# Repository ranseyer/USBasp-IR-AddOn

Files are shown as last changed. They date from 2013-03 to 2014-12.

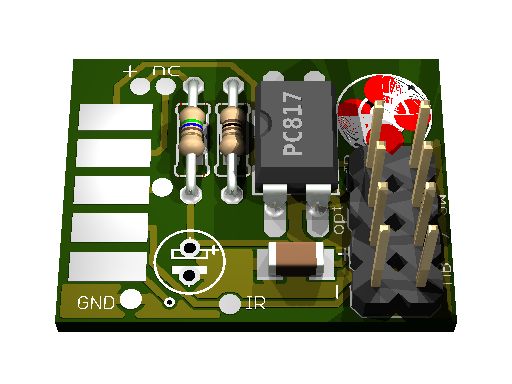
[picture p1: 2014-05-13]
HW/2.Medium/Add-OnV20-final-parts.jpg

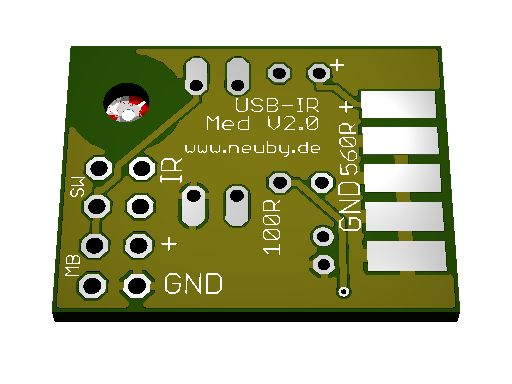
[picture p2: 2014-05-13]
HW/2.Medium/Add-OnV20-final-bot.jpg

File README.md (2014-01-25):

USBasp-IR-AddOn
===============

IR-Reciver  Extension for USBASP

ir_control, 1.0.0 (20.05.2012) control the "USB IR Remote Receiver"
 (www.mikrocontroller.net/articles/USB_IR_Remote_Receiver).

ir_control [-h] | [-V] | [[[-d] | [-p[1|0]] | [-rCOUNT] | [-s] | [-t]] [-i]]

  -h              print this help and exit
  -V              print version and exit

  -d              delete the PowerOn IR code.
                  The next received code becomes the new PowerOn code
  -p [1|0]        set PowerOn (ON=1/OFF=0)
  -r COUNT        set repeat count (default=5)
  -s              status of: PowerOn (ON=1/OFF=0)
  -i              ignore device name. (just checks the vendor:device ID)
                  needs one of the other options.

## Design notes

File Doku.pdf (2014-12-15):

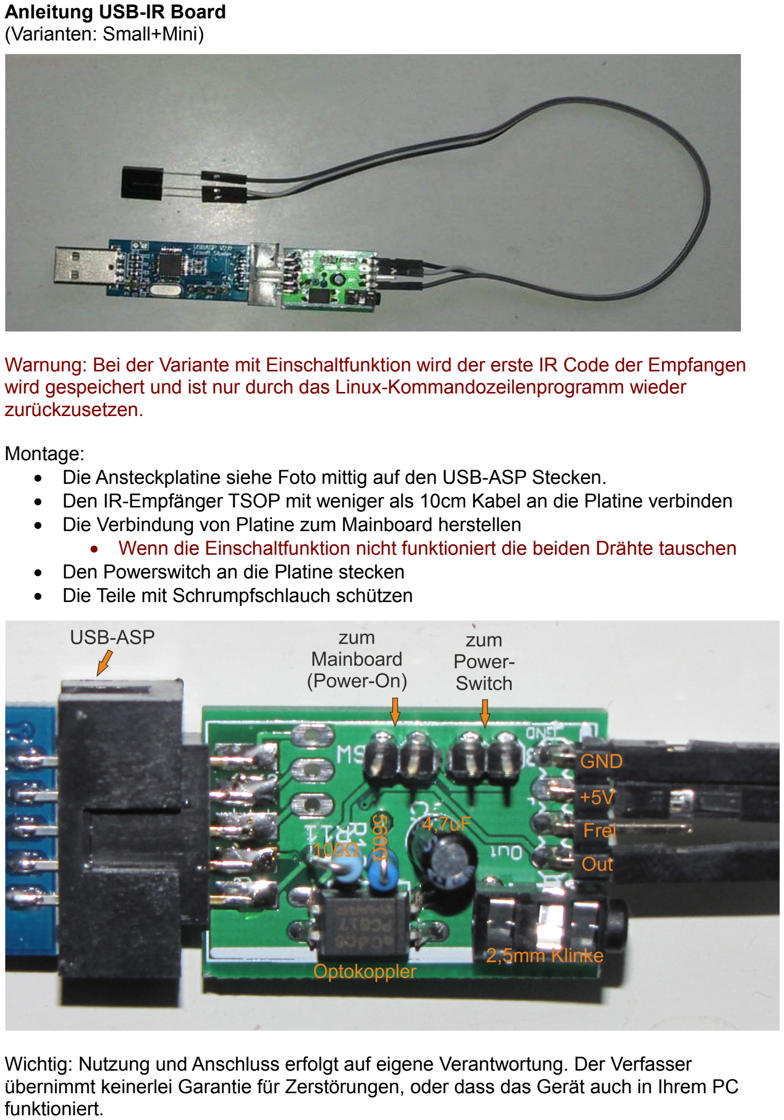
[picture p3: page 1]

Anleitung USB-IR Board
(Varianten: Small+Mini)

Warnung: Bei der Variante mit Einschaltfunktion wird der erste IR Code der Empfangen wird gespeichert und ist nur durch das Linux-Kommandozeilenprogramm wieder zurückzusetzen.

Montage:
- Die Ansteckplatine siehe Foto mittig auf den USB-ASP Stecken.
- Den IR-Empfänger TSOP mit weniger als 10cm Kabel an die Platine verbinden
- Die Verbindung von Platine zum Mainboard herstellen
- Wenn die Einschaltfunktion nicht funktioniert die beiden Drähte tauschen
- Den Powerswitch an die Platine stecken
- Die Teile mit Schrumpfschlauch schützen

Wichtig: Nutzung und Anschluss erfolgt auf eigene Verantwortung. Der Verfasser übernimmt keinerlei Garantie für Zerstörungen, oder dass das Gerät auch in Ihrem PC funktioniert.

Anschlussbelegung V2 Platine

Inbetriebnahme allgemein
A) Den „Stick“ einstecken und auf der Fernbediernung die Power-Taste drücken um den Einschaltcode anzulernen. Nach dem Anlernen den Stick kurz ziehen und wieder stecken. Der Einschaltcode wird nicht zum PC durchgereicht, sondern geht direkt zum Mainboardanschluss.
B) Wenn kein Einschaltcode genutzt werden soll, eine Taste einer unwichtigen Fernbedienung anlernen.
C) Stick ziehen und wieder einstecken

Inbetriebnahme Softwareseitig
Mögliche Varianten:
A) Bei easyVDR 2.0: einfach die Fragen bei der Installation korrekt beantworten
B) Andere Ubuntu/Debian Distributionen die Pakete von hier testen: https://launchpad.net/~martin-neuby/+archive/usb-irmp Diese sollten Versionsunabhängig sein...

Weitere Informationen / Links http://wiki.easy-vdr.de/index.php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 (http://www.vdr-portal.de/board18-vdr-hardware/board13-fernbedienungen/p1036294-irmplircd-f%C3%BCr-usb-ir-remote-receiver-based-on-irmp/)

V1.3 Martin Neubauer

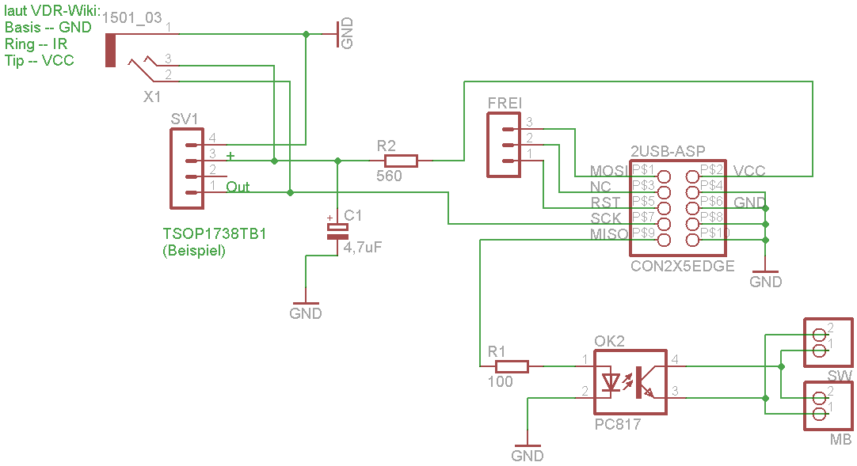
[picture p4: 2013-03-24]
HW/2.Medium/SchematicV13.png

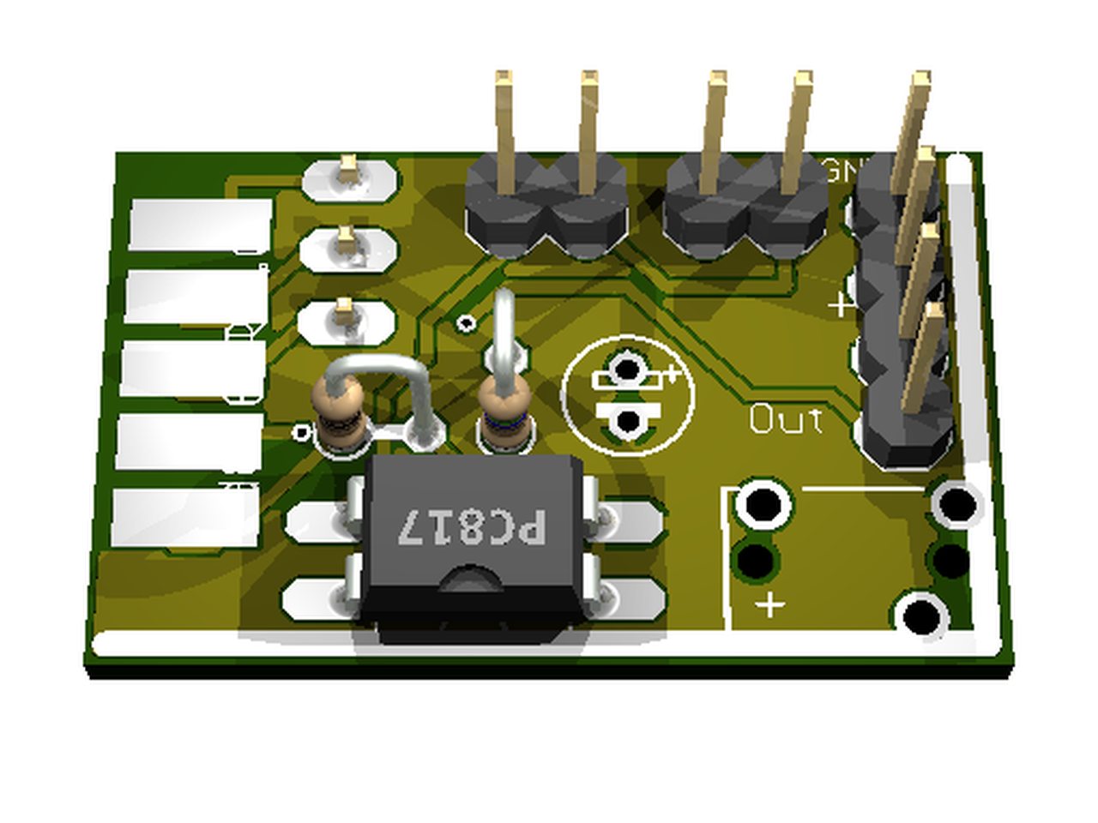
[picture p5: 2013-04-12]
HW/2.Medium/Add-OnV12-top.jpg

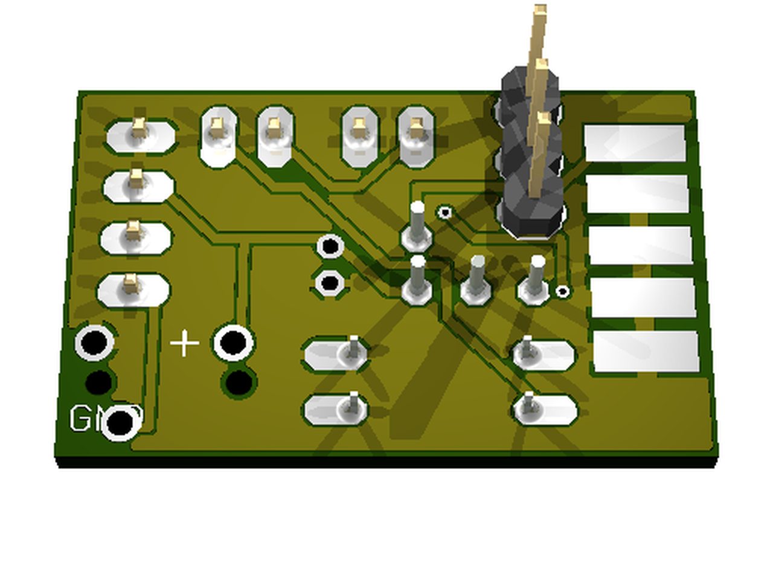
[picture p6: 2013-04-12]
HW/2.Medium/Add-OnV12-bot.jpg

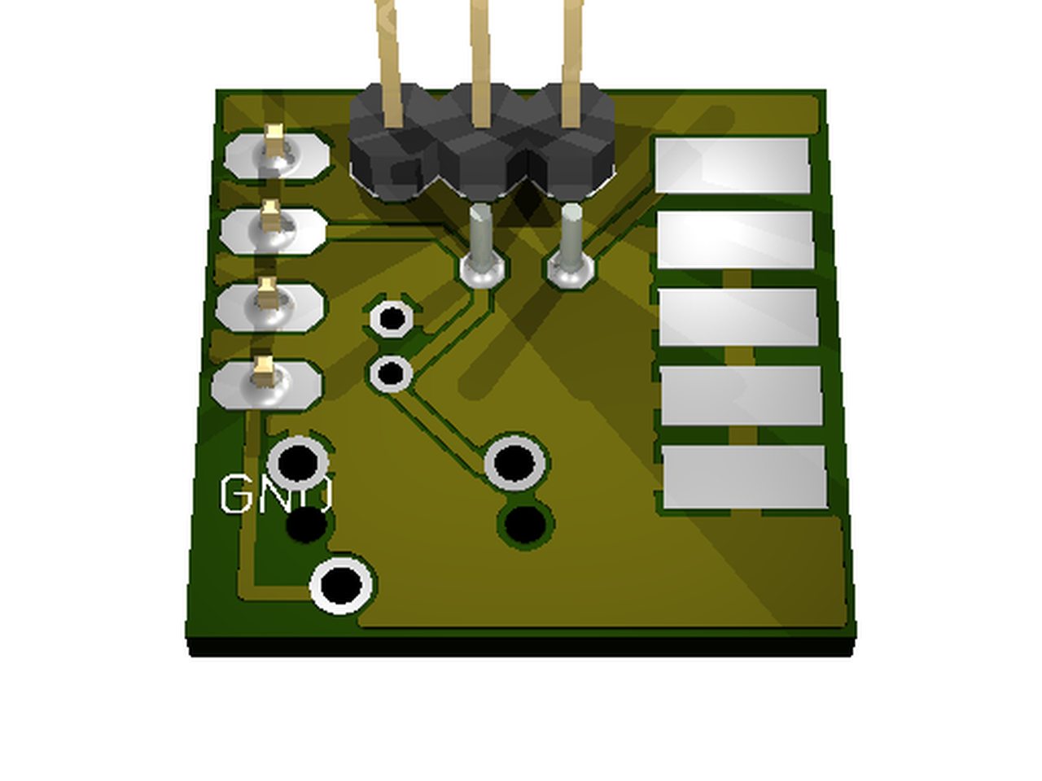
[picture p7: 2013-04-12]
HW/1.Mini/MiniAdd-OnV11-bot.jpg

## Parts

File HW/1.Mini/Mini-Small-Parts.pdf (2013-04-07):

### Tabelle1

Mini-Version

Part | | Device | | Preis
2USB-ASP CON2X5EDGE CON2X5EDGE | MPE 094-2-010 | 0,34
C1 | 4,7uF | CPOL-EUE1.8-4 SM 4,7/50RAD | 0,1
FREI | | MA03-1 | - | 0
R2 | | 560 R-EU_0204/2V | METALL 560 | 0,1
SV1 | | MA04-1 | SL 1X40G 2,54 (optional; Anteilig 10%) | 0,26
X1 | 1501_03 | 1501_03 | LUM 1501-03 | 0,7
Part | Device | Preis
2USB-ASP CON2X5EDGE CON2X5EDGE | SL 2X25G 2,54 (Anteilig 20%)
C1 | 4,7uF | CPOL-EUE1.8-4 SM 4,7/50RAD
FREI | | MA03-1 | optional
MB | | PINHD-1X2 | SL 1X40G 2,54 (optional; Anteilig 10%)
OK2 | PC817 | PC817 | PC 817X
R1 | | 100 R-EU_0204/2V | METALL 100
R2 | | 560 R-EU_0204/2V | METALL 560
SV1 | | MA04-1 | siehe MB
SW | | PINHD-1X2 | siehe MB
X1 | 1501_03 | 1501_03 | LUM 1501-03

Zusätzlich TSOP nach Wahl !

Partlist

Value | Reichelt
Partlist | Small-Version
Value | Reichelt

### Tabelle1

CON2X5EDGE | 1
E1,8-4 | 1
MA03-1 | 1
0204V | 1
MA04-1 | 1
1501_03 | 1
CON2X5EDGE | 1
E1,8-4 | 1
MA03-1 | 1
1X02 | 1
DIL04 | 1
0204V | 1
0204V | 1
MA04-1 | 1
1X02 | 1
1501_03 | 1
Package | Library | Sheet
| schwen rcl con-lstb rcl con-lstb

con-lumberg

Package | Library | Sheet
| schwen rcl con-lstb pinhead

optocoupler
| rcl rcl con-lstb pinhead

con-lumberg

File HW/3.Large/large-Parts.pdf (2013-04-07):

Tabelle1

Part | | Device | | Preis
C1 | 4u7 | C-EUC0805 | X5R-G0805 4,7 | 0,05
C2 | 10uF | CPOL-EU085CS-1AR | X7R-G1210 10 | 0,48
C3 | 100n | C-EUC0805 | X7R-G0603 100N0,05 | 0,05
C4 | 22p | C-EUC0805 | NPO-G0603 22P | 0,05
C5 | 22p | C-EUC0805 | | 0,05
CFG | | MA03-2 | SL 2X25G 2,54 (Anteilig 5%)
D1 | 3V6 | ZENER-DIODESOD80C | SMD ZF 3,6 | 0,05
D2 | 3V6 | ZENER-DIODESOD80C | SMD ZF 3,6 | 1,05
IC1 | MEGA48A-AU MEGA8-AI | ATMEGA 168A-AU
IR | | MA04-1 | SL 1X40G 2,54 (optional; Anteilig 10%)
ISP | | MA05-2 | SL 2X25G 2,54 (Anteilig 20%)
LED1 | | LEDCHIPLED_1206 | SMD-LED 1206 GN | 0,13
LED2 | | LEDCHIPLED_1206 | SMD-LED 1206 RT | 0,1
MB-SW | MA04-1 | SL 1X50W 2,54 oder SL 1X40G 2,54 (optional; Anteilig 10%) 0,1
OPT | | MA03-2 | Optional Teil von „SL 2X25G 2,54“ | 0,2
Q2 | | CRYSTALHC49UP | 12,0000-HC49-SMD | 0,24
R1 | | 68 R-EU_M0805 | SMD-0805 68,0 | 0,1
R2 | | 68 R-EU_M0805 | s.o. | 0,1
R3 | 2k2 | R-EU_M0805 | SMD-0805 2,20K | 0,1
R4 | 1k | R-EU_M0805 | SMD-0805 1,00K | 0,1
R5 | 1k | R-EU_M0805 | s.o. | 0,1
R6 | 10k | R-EU_M0805 | SMD-0805 10,0K | 0,1
R7 | 1k | R-EU_M0805 | s.o. | 0,1
R8 | 560 R-EU_M0805 | SMD-0805 560 | 0,1
R9 | 560 R-EU_M0805 | s.o. | 0,1
SV2 | | FE05W | MPE 094-1-005 | 0,26
X1 | 1501_031501_03 | LUM 1501-03 | 0,7
| | | Summe | 2,63
K2 | | 35701331 Optional SIL 7271-D 5V | 1,5
OK1 | PC817 PC817 | Optional PC 817X | 0,35
| 38KHz | TSOP 31238 | 0,77
| 56KHz | TSOP 31256 | 0,8

Partlist

Value | Reichelt

NPO-G0603 22P

green
red

Tabelle1

C0805
085CS_1AR
C0805
C0805
C0805
MA03-2
SOD80C
SOD80C
TQFP32-08
MA04-1
MA05-2
CHIPLED_1206
CHIPLED_1206
MA04-1
MA03-2
HC49UP
M0805
M0805
M0805
M0805
M0805
M0805
M0805
M0805
M0805
FE05W
1501_03

REED
DIL04
Package | Library
| rcl rcl rcl rcl rcl con-lstb diode diode atmel con-lstb con-lstb led led con-lstb con-lstb crystal rcl rcl rcl rcl rcl rcl rcl rcl rcl con-lsta con-lumberg

relay
optocoupler

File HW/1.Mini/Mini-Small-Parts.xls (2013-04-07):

Partlist | Mini-Version
Part | Value | Device | Reichelt | Preis | Package | Library | Sheet
2USB-ASP | CON2X5EDGE | CON2X5EDGE | MPE 094-2-010 | 0.34 | CON2X5EDGE | schwen | 1
C1 | 4,7uF | CPOL-EUE1.8-4 | SM 4,7/50RAD | 0.1 | E1,8-4 | rcl | 1
FREI |  | MA03-1 | - | 0 | MA03-1 | con-lstb | 1
R2 | 560 | R-EU_0204/2V | METALL 560 | 0.1 | 0204V | rcl | 1
SV1 |  | MA04-1 | SL 1X40G 2,54 (optional; Anteilig 10%) | 0.26 | MA04-1 | con-lstb | 1
X1 | 1501_03 | 1501_03 | LUM 1501-03 | 0.7 | 1501_03 | con-lumberg | 1
 |  |  | Summe | 1.5
Partlist | Small-Version
Part | Value | Device | Reichelt | Preis | Package | Library | Sheet
2USB-ASP | CON2X5EDGE | CON2X5EDGE | SL 2X25G 2,54 (Anteilig 20%) |  | CON2X5EDGE | schwen | 1
C1 | 4,7uF | CPOL-EUE1.8-4 | SM 4,7/50RAD |  | E1,8-4 | rcl | 1
FREI |  | MA03-1 | optional |  | MA03-1 | con-lstb | 1
MB |  | PINHD-1X2 | SL 1X40G 2,54 (optional; Anteilig 10%) |  | 1X02 | pinhead | 1
OK2 | PC817 | PC817 | Optional PC 817X |  | DIL04 | optocoupler | 1
R1 | 100 | R-EU_0204/2V | METALL 100 |  | 0204V | rcl | 1
R2 | 560 | R-EU_0204/2V | METALL 560 |  | 0204V | rcl | 1
SV1 |  | MA04-1 | siehe MB |  | MA04-1 | con-lstb | 1
SW |  | PINHD-1X2 | siehe MB |  | 1X02 | pinhead | 1
X1 | 1501_03 | 1501_03 | LUM 1501-03 |  | 1501_03 | con-lumberg | 1
Zusätzlich TSOP nach Wahl !
OK1 | PC817 | PC817 | Optional PC 817X | 0.35 | DIL04 | optocoupler
 | 38KHz |  | TSOP 31238 | 0.77
 | 56KHz |  | TSOP 31256 | 0.8

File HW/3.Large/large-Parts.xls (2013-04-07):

Partlist
Part | Value | Device | Reichelt | Preis | Package | Library
C1 | 4u7 | C-EUC0805 | X5R-G0805 4,7 | 0.05 | C0805 | rcl
C2 | 10uF | CPOL-EU085CS-1AR | X7R-G1210 10 | 0.48 | 085CS_1AR | rcl
C3 | 100n | C-EUC0805 | X7R-G0603 100N0,05 | 0.05 | C0805 | rcl
C4 | 22p | C-EUC0805 | NPO-G0603 22P | 0.05 | C0805 | rcl
C5 | 22p | C-EUC0805 | NPO-G0603 22P | 0.05 | C0805 | rcl
CFG |  | MA03-2 | SL 2X25G 2,54 (Anteilig 5%) |  | MA03-2 | con-lstb
D1 | 3V6 | ZENER-DIODESOD80C | SMD ZF 3,6 | 0.05 | SOD80C | diode
D2 | 3V6 | ZENER-DIODESOD80C | SMD ZF 3,6 | 1.05 | SOD80C | diode
IC1 | MEGA48A-AU | MEGA8-AI | ATMEGA 168A-AU |  | TQFP32-08 | atmel
IR |  | MA04-1 | SL 1X40G 2,54 (optional; Anteilig 10%) |  | MA04-1 | con-lstb
ISP |  | MA05-2 | SL 2X25G 2,54 (Anteilig 20%) |  | MA05-2 | con-lstb
LED1 | green | LEDCHIPLED_1206 | SMD-LED 1206 GN | 0.13 | CHIPLED_1206 | led
LED2 | red | LEDCHIPLED_1206 | SMD-LED 1206 RT | 0.1 | CHIPLED_1206 | led
MB-SW |  | MA04-1 | SL 1X50W 2,54 oder SL 1X40G 2,54 (optional; Anteilig 10%) | 0.1 | MA04-1 | con-lstb
OPT |  | MA03-2 | Optional Teil von „SL 2X25G 2,54“ | 0.2 | MA03-2 | con-lstb
Q2 |  | CRYSTALHC49UP | 12,0000-HC49-SMD | 0.24 | HC49UP | crystal
R1 | 68 | R-EU_M0805 | SMD-0805 68,0 | 0.1 | M0805 | rcl
R2 | 68 | R-EU_M0805 | s.o. | 0.1 | M0805 | rcl
R3 | 2k2 | R-EU_M0805 | SMD-0805 2,20K | 0.1 | M0805 | rcl
R4 | 1k | R-EU_M0805 | SMD-0805 1,00K | 0.1 | M0805 | rcl
R5 | 1k | R-EU_M0805 | s.o. | 0.1 | M0805 | rcl
R6 | 10k | R-EU_M0805 | SMD-0805 10,0K | 0.1 | M0805 | rcl
R7 | 1k | R-EU_M0805 | s.o. | 0.1 | M0805 | rcl
R8 | 560 | R-EU_M0805 | SMD-0805 560 | 0.1 | M0805 | rcl
R9 | 560 | R-EU_M0805 | s.o. | 0.1 | M0805 | rcl
SV2 |  | FE05W | MPE 094-1-005 | 0.26 | FE05W | con-lsta
X1 | 1501_03 | 1501_03 | LUM 1501-03 | 0.7 | 1501_03 | con-lumberg
 |  |  | Summe | 2.63
K2 |  | 35701331 | Optional SIL 7271-D 5V | 1.5 | REED | relay
OK1 | PC817 | PC817 | Optional PC 817X | 0.35 | DIL04 | optocoupler
 | 38KHz |  | TSOP 31238 | 0.77
 | 56KHz |  | TSOP 31256 | 0.8

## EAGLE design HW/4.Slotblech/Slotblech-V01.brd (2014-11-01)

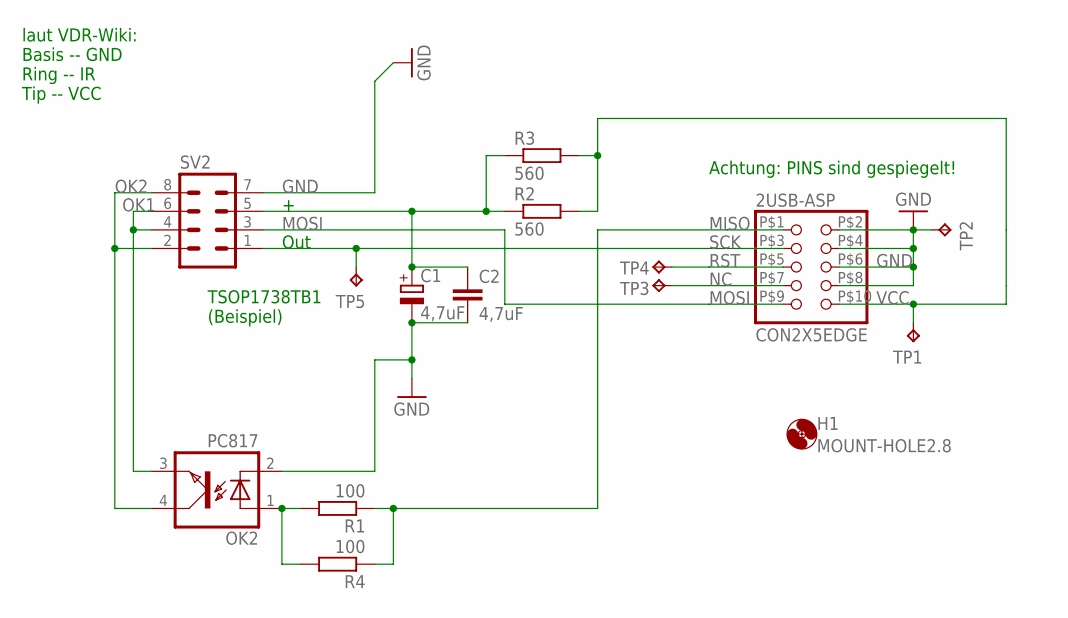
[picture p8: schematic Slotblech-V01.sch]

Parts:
2USB-ASP: CON2X5EDGE
C1: 4,7uF; E1,8-4
C2: 4,7uF; C1206K
H1: MOUNT-HOLE2.8; 2,8
OK2: PC817; DIL04
R1: 100; 0204/7
R2: 560; 0204/7
R3: 560; R0805W
R4: 100; R0805W
SV2: MA04-2
TP1, TP2, TP3, TP4, TP5: TPB1,27; B1,27

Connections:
GND: 2USB-ASP.P$2 (2), 2USB-ASP.P$4 (4), 2USB-ASP.P$6 (6), 2USB-ASP.P$8 (8), C1.-, C2.2, OK2.2 (C), SV2.7, TP2.TP
MISO: 2USB-ASP.P$1 (1), R1.1, R4.1
MOSI: 2USB-ASP.P$9 (9), SV2.3
unnamed: C1.+, C2.1, R2.1, R3.1, SV2.5
unnamed: OK2.1 (A), R1.2, R4.2
NC: 2USB-ASP.P$7 (7), TP3.TP
OK1: OK2.3 (EMIT), SV2.4, SV2.6
OK2: OK2.4 (COL), SV2.2, SV2.8
RST: 2USB-ASP.P$5 (5), TP4.TP
SCK: 2USB-ASP.P$3 (3), SV2.1, TP5.TP
VCC: 2USB-ASP.P$10 (10), R2.2, R3.2, TP1.TP

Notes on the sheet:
Achtung: PINS sind gespiegelt!
Out
laut VDR-Wiki: Basis -- GND Ring -- IR Tip -- VCC
TSOP1738TB1 (Beispiel)

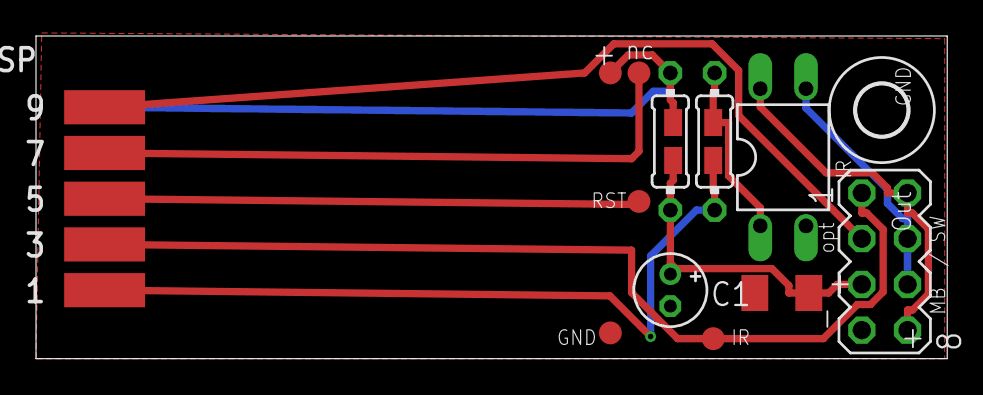
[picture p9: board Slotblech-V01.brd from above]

Board: 2 copper layers, 50.6 x 17.9 mm, 15 parts (0 on the bottom side), 11 nets.

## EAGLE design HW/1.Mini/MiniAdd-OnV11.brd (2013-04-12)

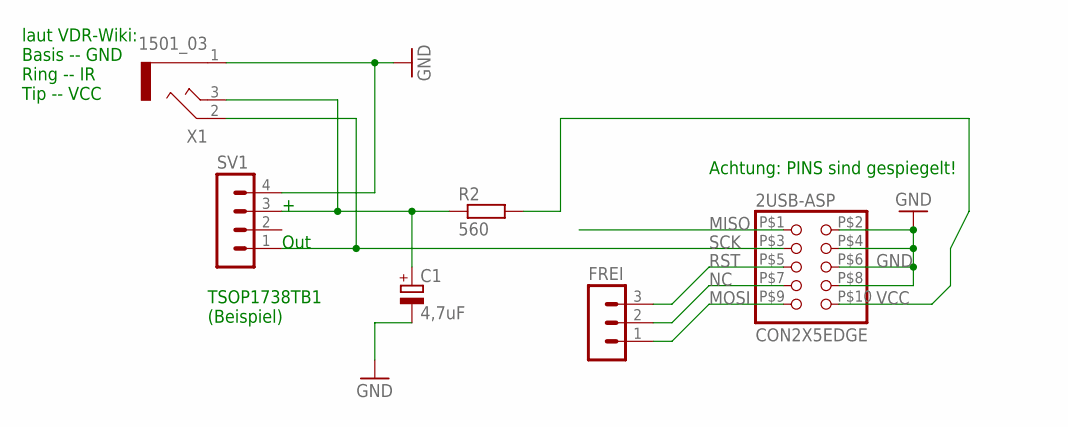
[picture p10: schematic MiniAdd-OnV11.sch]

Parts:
2USB-ASP: CON2X5EDGE
C1: 4,7uF; E1,8-4
FREI: MA03-1
R2: 560; 0204V
SV1: MA04-1
X1: 1501_03

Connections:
GND: 2USB-ASP.P$2 (2), 2USB-ASP.P$4 (4), 2USB-ASP.P$6 (6), 2USB-ASP.P$8 (8), C1.-, SV1.4, X1.1
MISO: 2USB-ASP.P$1 (1)
MOSI: 2USB-ASP.P$9 (9), FREI.1
unnamed: C1.+, R2.1, SV1.3, X1.3
NC: 2USB-ASP.P$7 (7), FREI.2
RST: 2USB-ASP.P$5 (5), FREI.3
SCK: 2USB-ASP.P$3 (3), SV1.1, X1.2
VCC: 2USB-ASP.P$10 (10), R2.2

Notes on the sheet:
Achtung: PINS sind gespiegelt!
Out
laut VDR-Wiki: Basis -- GND Ring -- IR Tip -- VCC
TSOP1738TB1 (Beispiel)

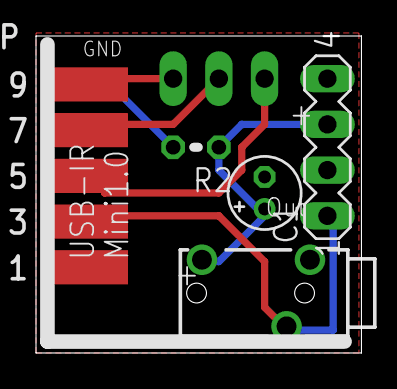
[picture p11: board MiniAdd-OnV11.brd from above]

Board: 2 copper layers, 18.1 x 17.6 mm, 6 parts (1 on the bottom side), 7 nets.

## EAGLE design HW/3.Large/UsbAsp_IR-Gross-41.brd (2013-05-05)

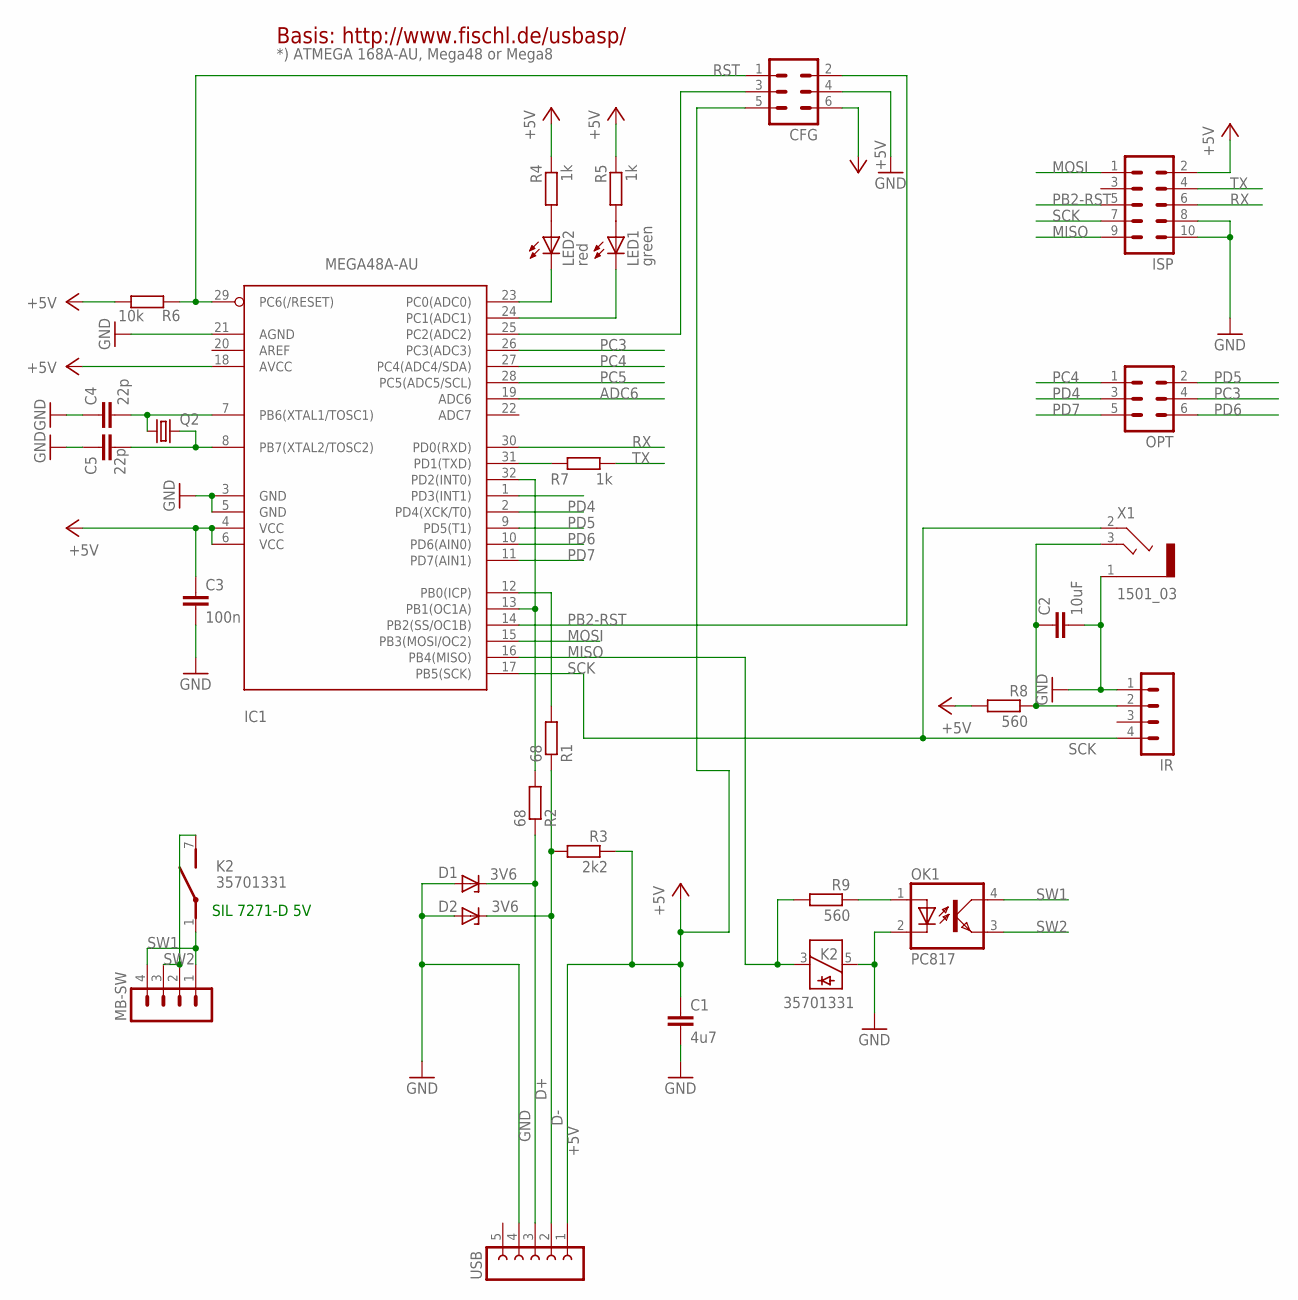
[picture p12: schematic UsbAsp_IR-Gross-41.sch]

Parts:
C1: 4u7; C0805
C2: 10uF; C1210
C3: 100n; C0805
C4, C5: 22p; C0805
CFG: MA03-2
D1, D2: 3V6; SOD80C
IC1: MEGA48A-AU; TQFP32-08
IR: MA04-1
ISP: MA05-2
K2: 35701331; REED
LED1: green; CHIPLED_1206
LED2: red; CHIPLED_1206
MB-SW: MA04-1
OK1: PC817; DIL04
OPT: MA03-2
Q2: CRYSTALHC49UP; HC49UP
R1, R2: 68; M0805
R3: 2k2; M0805
R4, R5, R7: 1k; M0805
R6: 10k; M0805
R8, R9: 560; M0805
USB: FE05W
X1: 1501_03

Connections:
+5V: C1.1, C3.1, CFG.5, CFG.6, IC1.4 (VCC), IC1.6 (VCC), IC1.18 (AVCC), ISP.2, R3.1, R4.1, R5.1, R6.1, R8.2, USB.1
ADC6: IC1.19 (ADC6)
D+: D1.C, R2.1, USB.3
D-: D2.C, R1.1, R3.2, USB.2
GND: C1.2, C2.2, C3.2, C4.1, C5.1, CFG.4, D1.A, D2.A, IC1.3 (GND), IC1.5 (GND), IC1.21 (AGND), IR.1, ISP.8, ISP.10, K2.5, OK1.2 (C), USB.4, X1.1
MISO: IC1.16 (PB4(MISO)), ISP.9, K2.3, R9.2
MOSI: IC1.15 (PB3(MOSI/OC2)), ISP.1
unnamed: OK1.1 (A), R9.1
unnamed: CFG.3, IC1.25 (PC2(ADC2))
unnamed: C2.1, IR.2, R8.1, X1.3
unnamed: IC1.31 (PD1(TXD)), R7.2
unnamed: IC1.13 (PB1(OC1A)), IC1.32 (PD2(INT0)), R2.2
unnamed: LED2.A, R4.2
unnamed: IC1.23 (PC0(ADC0)), LED2.C
unnamed: IC1.24 (PC1(ADC1)), LED1.C
unnamed: IC1.12 (PB0(ICP)), R1.2
unnamed: C4.2, IC1.7 (PB6(XTAL1/TOSC1)), Q2.1
unnamed: C5.2, IC1.8 (PB7(XTAL2/TOSC2)), Q2.2
unnamed: LED1.A, R5.2
PB2-RST: CFG.2, IC1.14 (PB2(SS/OC1B)), ISP.5
PC3: IC1.26 (PC3(ADC3)), OPT.4
PC4: IC1.27 (PC4(ADC4/SDA)), OPT.1
PC5: IC1.28 (PC5(ADC5/SCL))
PD4: IC1.2 (PD4(XCK/T0)), OPT.3
PD5: IC1.9 (PD5(T1)), OPT.2
PD6: IC1.10 (PD6(AIN0)), OPT.6
PD7: IC1.11 (PD7(AIN1)), OPT.5
RST: CFG.1, IC1.29 (PC6(/RESET)), R6.2
RX: IC1.30 (PD0(RXD)), ISP.6
SCK: IC1.17 (PB5(SCK)), IR.4, ISP.7, X1.2
SW1: K2.1, MB-SW.1, MB-SW.4, OK1.4 (COL)
SW2: K2.7 (S), MB-SW.2, MB-SW.3, OK1.3 (EMIT)
TX: ISP.4, R7.1

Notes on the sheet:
Basis: http://www.fischl.de/usbasp/
*) ATMEGA 168A-AU, Mega48 or Mega8
SIL 7271-D 5V

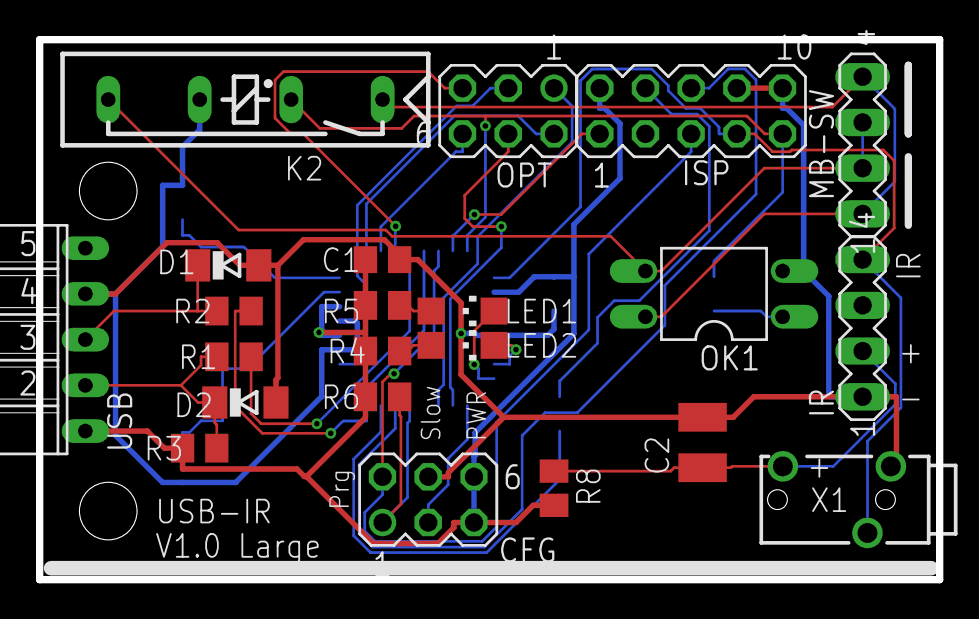
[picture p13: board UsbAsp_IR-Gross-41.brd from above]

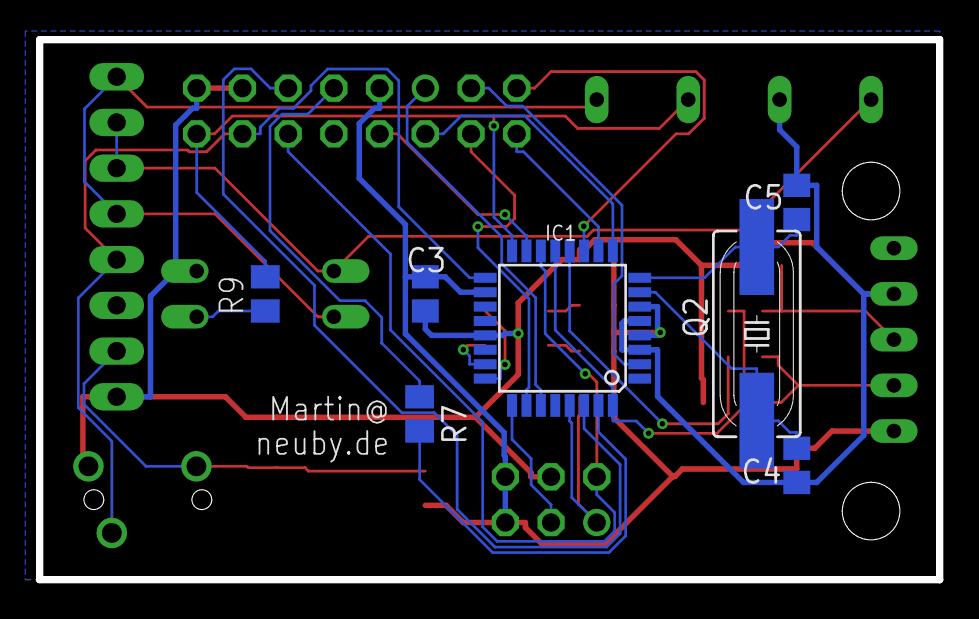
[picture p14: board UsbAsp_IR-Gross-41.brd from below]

Board: 2 copper layers, 50.0 x 30.0 mm, 29 parts (7 on the bottom side), 31 nets.

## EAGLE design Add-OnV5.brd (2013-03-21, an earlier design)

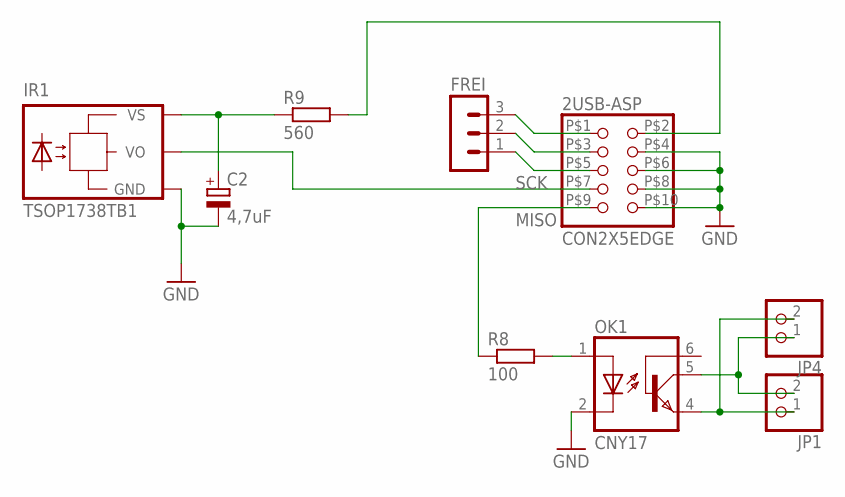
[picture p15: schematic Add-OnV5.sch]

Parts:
2USB-ASP: CON2X5EDGE
C2: 4,7uF; E1,8-4
FREI: MA03-1
IR1: TSOP1738TB1; TSOP17_TB1
JP1, JP4: PINHD-1X2; 1X02
OK1: CNY17; DIL06
R8: 100; 0204/7
R9: 560; 0204/7

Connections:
GND: 2USB-ASP.P$4 (4), 2USB-ASP.P$6 (6), 2USB-ASP.P$8 (8), 2USB-ASP.P$10 (10), C2.-, IR1.GND, OK1.2 (C)
MISO: 2USB-ASP.P$9 (9), R8.1
unnamed: C2.+, IR1.VS, R9.1
unnamed: OK1.1 (A), R8.2
unnamed: JP1.2, JP4.1, OK1.5 (COL)
unnamed: JP1.1, JP4.2, OK1.4 (EMI)
unnamed: 2USB-ASP.P$2 (2), R9.2
unnamed: 2USB-ASP.P$5 (5), FREI.1
unnamed: 2USB-ASP.P$3 (3), FREI.2
unnamed: 2USB-ASP.P$1 (1), FREI.3
SCK: 2USB-ASP.P$7 (7), IR1.VO

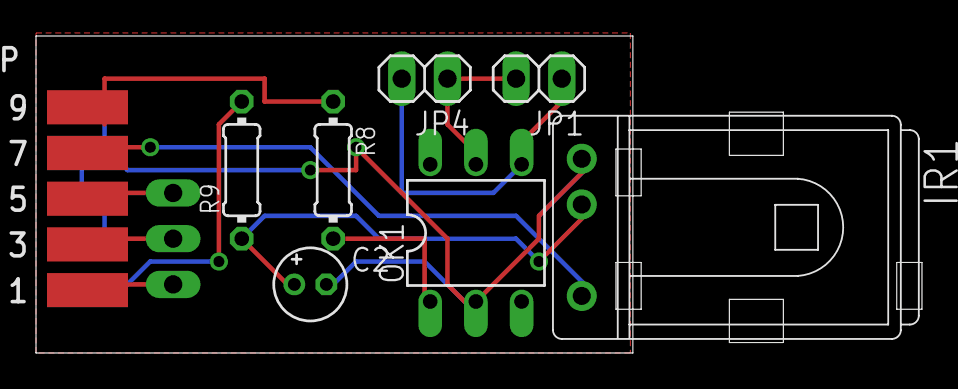
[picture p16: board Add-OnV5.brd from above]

Board: 2 copper layers, 33.2 x 17.6 mm, 9 parts (1 on the bottom side), 11 nets.

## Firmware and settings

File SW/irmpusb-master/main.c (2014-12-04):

/* Name: main.c
 * Project: USB IR Remote Receiver with V-USB and Irmp
 * Author: Portisch
 * Creation Date: 15.03.2010
 * Copyright: (c) 2010 by Portisch
 * License: GNU GPL v2 (see License.txt), GNU GPL v3 or proprietary (CommercialLicense.txt)
 */

/*
This example should run on most AVRs with only little changes. No special
hardware resources except INT0 are used. You may have to change usbconfig.h for
different I/O pins for USB. Please note that USB D+ must be the INT0 pin, or
at least be connected to INT0 as well.
*/

#include <avr/io.h>
#include <avr/wdt.h>		/* watchdog */
#include <avr/interrupt.h>  /* for sei() */
#include <util/delay.h>     /* for _delay_ms() */
#include <avr/eeprom.h>
#include <string.h> 		/* for memcpy */

#include "configUSBIRRemoteReceiver.h"	/* main config file */

#include "irmp/irmp.h"			/* ir remote handling */

#include <avr/pgmspace.h>   /* required by usbdrv.h */
#include "usbdrv.h"			/* v-usb driver */

#ifndef F_CPU
	#error F_CPU unkown
#endif

//enter here the Irmp build date or version:
const char IrmpVersion[] = "2.2.3";

#define led1On()    PORTC &= ~(1 << PC1)
#define led1Off()   PORTC |= (1 << PC1)
#define led2On()  	PORTC &= ~(1 << PC0)
#define led2Off() 	PORTC |= (1 << PC0)
 

/* ------------------------------------------------------------------------- */
/* ----------------------------- USB interface ----------------------------- */
/* ------------------------------------------------------------------------- */

const PROGMEM char usbHidReportDescriptor[USB_CFG_HID_REPORT_DESCRIPTOR_LENGTH] = {
    0x05, 0x01,                    // USAGE_PAGE (Generic Desktop)
    0x0b, 0x01, 0x00, 0x00, 0xff,  // USAGE (Vendor Defined Page 1:Vendor Usage 1)
    0xa1, 0x01,                    // COLLECTION (Application)
    0x15, 0x00,                    //   LOGICAL_MINIMUM (0)
    0x26, 0xff, 0x00,              //   LOGICAL_MAXIMUM (255)
    0x75, 0x08,                    //   REPORT_SIZE (8)
    0x85, 0x01,                    //   REPORT_ID (1)
    0x95, 0x06,                    //   REPORT_COUNT (6)
    0x09, 0x00,                    //   USAGE (Undefined)
    0x82, 0x00, 0x01,              //   INPUT (Data,Ary,Abs,Buf)
    0x85, 0x02,                    //   REPORT_ID (2)
    0x95, 0x01,                    //   REPORT_COUNT (1)
    0x09, 0x00,                    //   USAGE (Undefined)
    0xb2, 0x02, 0x01,              //   FEATURE (Data,Var,Abs,Buf)
    0x85, 0x03,                    //   REPORT_ID (3)
    0x95, 0x06,                    //   REPORT_COUNT (6)
    0x09, 0x00,                    //   USAGE (Undefined)
    0xb2, 0x02, 0x01,              //   FEATURE (Data,Var,Abs,Buf)
    0x85, 0x04,                    //   REPORT_ID (4)
    0x95, 0x01,                    //   REPORT_COUNT (1)
    0x09, 0x00,                    //   USAGE (Undefined)
    0xb2, 0x02, 0x01,              //   FEATURE (Data,Var,Abs,Buf)
    0x85, 0x05,                    //   REPORT_ID (5)
    0x95, 0x06,                    //   REPORT_COUNT (6)
    0x09, 0x00,                    //   USAGE (Undefined)
    0xb2, 0x02, 0x01,              //   FEATURE (Data,Var,Abs,Buf)
    0x85, 0x06,                    //   REPORT_ID (6)
    0x95, 0x02,                    //   REPORT_COUNT (2)
    0x09, 0x00,                    //   USAGE (Undefined)
    0xb2, 0x02, 0x01,              //   FEATURE (Data,Var,Abs,Buf)
    0x85, 0x07,                    //   REPORT_ID (7)
    0x95, 0x04,                    //   REPORT_COUNT (4)
    0x09, 0x00,                    //   USAGE (Undefined)
    0xb2, 0x02, 0x01,              //   FEATURE (Data,Var,Abs,Buf)
    0x85, 0x08,                    //   REPORT_ID (8)
    0x95, 0x01,                    //   REPORT_COUNT (1)
    0x09, 0x00,                    //   USAGE (Undefined)
    0xb2, 0x02, 0x01,              //   FEATURE (Data,Var,Abs,Buf)
#if USE_BOOTLOADER
    0x85, 0x09,                    //   REPORT_ID (9)
    0x95, 0x01,                    //   REPORT_COUNT (1)
    0x09, 0x00,                    //   USAGE (Undefined)
    0xb2, 0x02, 0x01,              //   FEATURE (Data,Var,Abs,Buf)
#endif
# if IRMP_LOGGING
    0x85, 0x0A,                    //   REPORT_ID (10)
    0x95, 0x02,                    //   REPORT_COUNT (2)
    0x09, 0x00,                    //   USAGE (Undefined)
    0x82, 0x00, 0x01,              //   INPUT (Data,Ary,Abs,Buf)
	
    0x85, 0x0B,                    //   REPORT_ID (11)
    0x96, 0xBC, 0x02,              //   REPORT_COUNT (700)
    0x09, 0x00,                    //   USAGE (Undefined)
    0xb2, 0x02, 0x01,              //   FEATURE (Data,Var,Abs,Buf)
#endif	
    0xc0                           // END_COLLECTION
};

/* The following variables store the status of the current data transfer */
static uchar			currentAddress   	= 0;
static unsigned short	bytesRemaining   	= 0;
static uchar			PowerOnEnabled   	= TRUE;

/* const for V-USB feature report ID handling */
const uchar	  NewIRCodeAvailable = 1;
const uchar	  ReadPowerOnEnabled = 2;
const uchar	  ReadTrainendIRCode = 3;
const uchar	  SetPowerOnEnabled  = 4;
const uchar	  SetTrainedIRCode 	 = 5;
//const uchar	  SetIRPollingTime   = 6;
const uchar	  ReadIrmpVersion    = 7;
const uchar	  SetMinRepeats 	 = 8;
#if USE_BOOTLOADER
const uchar	  ResetForBootloader = 9;
#endif
# if IRMP_LOGGING
const uchar	  NewLogAvailable	 = 10;
const uchar	  ReadLogData		 = 11;
#endif

static uchar  DoWriteReport		 = 0;
static uchar  DoReadReport		 = 0;

/* Memory addresses in eeprom */
static uchar 	AdressPowerOn		= 0;
static uchar 	AdressTrainedCode 	= 1;
static uchar	AdressMinRepeats	= 7;
#if USE_BOOTLOADER
static uchar	AdressBootloader	= 8;
static uchar	EnableBootloader	= 1;
static uchar	DisableBootloader	= 0;
#endif

/* reapeat counters for received IR codes */
static uchar	RepeatCounter		= 0;
static uchar	MinRepeats			= 5;	// default minimum repeat counter

static IRMP_DATA irmp_data;
static IRMP_DATA trained_irmp_data;

/* reply buffer should be big enough to cover also the irmp version ! */
static uchar    replyBuf[16];

/* ------------------------------------------------------------------------- */
/* main functions for irmp
 */
void
timer_init (void)
{
																			/* IR polling timer */		
	TCCR1B  = (1 << WGM12) | (1 << CS10);									// switch CTC Mode on, set prescaler to 1

	// may adjust IR polling rate here to optimize IR receiving:
	OCR1A   =  (F_CPU / F_INTERRUPTS) - 1;                                  // compare value: 1/10000 of CPU frequency

	// enable Timer1 for IR polling
	#if defined (__AVR_ATmega8__) || defined (__AVR_ATmega16__) || defined (__AVR_ATmega32__) || defined (__AVR_ATmega64__) || defined (__AVR_ATmega162__)
		TIMSK = 1 << OCIE1A;   												// Timer1A ISR activate 		
	#else										 				
		TIMSK1  = 1 << OCIE1A;                 								// Timer1A ISR activate
	#endif	// __AVR...
}

/*---------------------------------------------------------------------------------------------------------------------------------------------------
 * init all io pins of the AVR, first all to input with pullups. then config USB and output pin
 *---------------------------------------------------------------------------------------------------------------------------------------------------
 */
void 
init_io(void) 
{
	/* first set all pins to input */
    PORTB = 0xFF;   													/* activate all pull-ups */
    DDRB = 0;       													/* all pins input */
    PORTD = 0xFF;   													/* activate all pull-ups */
    DDRD = 0;    														/* all pins input */

    PORTD &=~(1<<PD2);													/* deactivate pull-up on int0 line */

	/* all inputs except PC0, PC1 */
	DDRC = 0x03;
	PORTC = 0xfe;

	/* USB pins */
	USBOUT ^= _BV (USB_CFG_DMINUS_BIT) | _BV (USB_CFG_DPLUS_BIT);   	/* deactivate pull-ups on USB lines */

	#if USE_PowerOnFunction
		/* config PowerOn pin */
		SWITCH_PORT ^=	_BV (SWITCH_BIT);								/* deactivate pull-ups on PowerOn pin */ 	
		SWITCH_DDR ^= _BV (SWITCH_BIT);									/* set switch pin as digital output */
	#endif
}
 

/*---------------------------------------------------------------------------------------------------------------------------------------------------
 * timer 1 compare handler, should be called every 1/10000 sec
 *---------------------------------------------------------------------------------------------------------------------------------------------------
 */
void TIMER1_COMPA_vect(void) __attribute__((interrupt));
void TIMER1_COMPA_vect(void)
{
	/* ------------------------------------------------------------------------- */
	/* main functions for irmp
	 */
  	irmp_ISR();                                                     // call irmp ISR
  	// call other timer interrupt routines...
}

/* ------------------------------------------------------------------------- */

/* usbFunctionRead() is called when the host requests a chunk of data from
 * the device. For more information see the documentation in usbdrv/usbdrv.h.
 */
uchar   usbFunctionRead(uchar *data, uchar len)
{
    if(len > bytesRemaining)
        len = bytesRemaining;
		
	if ( DoReadReport == ReadIrmpVersion)
	{
		memcpy(data, &replyBuf[currentAddress], len);	
	}
	#if IRMP_LOGGING
	else if ( DoReadReport == ReadLogData )
	{
		memcpy(data, &buf[currentAddress], len);
	}
	#endif

    currentAddress += len;
    bytesRemaining -= len;
    return len;
}

/* ------------------------------------------------------------------------- */

/* usbFunctionWrite() is called when the host sends a chunk of data to the
 * device. For more information see the documentation in usbdrv/usbdrv.h.
 */
uchar   usbFunctionWrite(uchar *data, uchar len)
{
    if(bytesRemaining == 0)
        return 1;               /* end of transfer */
    if(len > bytesRemaining)
        len = bytesRemaining;

	if ( DoWriteReport == SetPowerOnEnabled )
	{
		eeprom_write_block(&data[1], (uchar *)0 + currentAddress, len);						// store new value of PowerOn in eeprom
		memcpy(&PowerOnEnabled, &data[1], sizeof(PowerOnEnabled));							// update PowerOn flag:			
	}
	else if ( DoWriteReport == SetTrainedIRCode )
	{
		eeprom_write_block(&data[1], (uchar *)0 + currentAddress, len);						// store new trained IR code in eeprom
		memcpy(&trained_irmp_data, &data[1], sizeof(trained_irmp_data));					// update trained IR code:
	} 
	/*
	else if ( DoWriteReport == SetIRPollingTime )
	{
		OCR1A = (F_CPU / ((data[2] << 8 ) | data[1])) - 1;									// update new IR polling time, data[1-2] = new frequency
	} 
	*/
	else if ( DoWriteReport == SetMinRepeats )
	{
		eeprom_write_block(&data[1], (uchar *)0 + currentAddress, len);						// store new MinRepeats in eeprom
		memcpy(&MinRepeats, &data[1], sizeof(MinRepeats));									// update new MinRepeats received from host
	} 
    currentAddress += len;
    bytesRemaining -= len;
    return bytesRemaining == 0; 															/* return 1 if this was the last chunk */
}


/* ------------------------------------------------------------------------- */

uchar   usbFunctionSetup(uchar data[8]) 
{ 

usbRequest_t    *rq = (void *)data;

    if((rq->bmRequestType & USBRQ_TYPE_MASK) == USBRQ_TYPE_CLASS){    // HID class request 
        if(rq->bRequest == USBRQ_HID_GET_REPORT){  // wValue: ReportType (highbyte), ReportID (lowbyte)

		usbMsgPtr = replyBuf;

            if(rq->wValue.bytes[0] == ReadPowerOnEnabled){ 									/* ReportID 2 ReadPowerOnEnabled */ 
				memcpy(&replyBuf[0], &rq->wValue.bytes[0], sizeof(uchar));					// copy report id
				eeprom_read_block(&replyBuf[1], (uchar *)0 +AdressPowerOn, sizeof(PowerOnEnabled));		// copy PowerOn flag to reply buffer 
                return sizeof(PowerOnEnabled) + sizeof(uchar);  							// 1 bytes PowerOnEnabled struct + 1 byte ID

            }else if(rq->wValue.bytes[0] == ReadTrainendIRCode){ 							/* ReportID 3 ReadTrainendIRCode */ 
				memcpy(&replyBuf[0], &rq->wValue.bytes[0], sizeof(uchar));					// copy report id
				eeprom_read_block(&replyBuf[1], (uchar *)0 +AdressTrainedCode, sizeof(trained_irmp_data));		// copy trained IR code to reply buffer  
                return (sizeof(trained_irmp_data) + sizeof(uchar));							// 6 bytes irmp struct + 1 byte ID

            }else if(rq->wValue.bytes[0] == ReadIrmpVersion){ 								/* ReportID 7 ReadIrmpVersion */ 
				memcpy(&replyBuf[0], &rq->wValue.bytes[0], sizeof(uchar));					// copy report id
				memcpy(&replyBuf[1], &IrmpVersion, sizeof(IrmpVersion));					// copy Irmp version			
	            bytesRemaining = sizeof(IrmpVersion);
	            currentAddress = 0;
				DoReadReport = ReadIrmpVersion;
	            return USB_NO_MSG;  														// use usbFunctionRead() to obtain data
			#if IRMP_LOGGING
            }else if(rq->wValue.bytes[0] == ReadLogData){ 									/* ReportID 11 ReadLogData */
	            bytesRemaining = sizeof(buf);
	            currentAddress = 0;
				DoReadReport = ReadLogData;
	            return USB_NO_MSG;  														// use usbFunctionRead() to obtain data				
			#endif
            }	 
        }else if(rq->bRequest == USBRQ_HID_SET_REPORT){ 
            if(rq->wValue.bytes[0] == SetPowerOnEnabled){   								/* ReportID 4 SetPowerOnEnabled */	
	            bytesRemaining = sizeof(PowerOnEnabled);									//store PowerOnEnabled in EEProm:
	            currentAddress = (int)AdressPowerOn;
				DoWriteReport = SetPowerOnEnabled;											// set report id flag for usbFunctionWrite
	            return USB_NO_MSG;  														// use usbFunctionWrite() to receive data from host	
            }else if(rq->wValue.bytes[0] == SetTrainedIRCode){  							/* ReportID 5 SetTrainedIRCode */
			    bytesRemaining = sizeof(trained_irmp_data);									// store IR Code in EEProm
	            currentAddress = (int)AdressTrainedCode;
				DoWriteReport = SetTrainedIRCode;											// set report id flag for usbFunctionWrite
	            return USB_NO_MSG;  														// use usbFunctionWrite() to receive data from host	    
			/*
            }else if(rq->wValue.bytes[0] == SetIRPollingTime){  							// ReportID 6 SetIRPollingTime 				
	            bytesRemaining = sizeof(OCR1A);												// update new IR polling time
				DoWriteReport = SetIRPollingTime;											// set report id flag for usbFunctionWrite
	            return USB_NO_MSG;  														// use usbFunctionWrite() to receive data from host	
			*/
            }else if(rq->wValue.bytes[0] == SetMinRepeats){  								/* ReportID 8 SetMinRepeats */				
				currentAddress = (int)AdressMinRepeats;
	            bytesRemaining = sizeof(MinRepeats);										// update new max repeat counter
				DoWriteReport = SetMinRepeats;												// set report id flag for usbFunctionWrite
	            return USB_NO_MSG;  														// use usbFunctionWrite() to receive data from host	
		#if USE_BOOTLOADER
            }else if(rq->wValue.bytes[0] == ResetForBootloader){  							/* ReportID 9 host is requesting the bootloader */				
				eeprom_write_block(&EnableBootloader, (uchar *)0 + AdressBootloader, sizeof(uchar));					
				for(;;);   																	// Reset from watchdog	            
		#endif
            }			    			         
		}
    }else{ 
        // ignore vendor type requests, we don't use any
    } 
    return 0; 
} 
/* ------------------------------------------------------------------------- */
void SendINTData(void)
{
	
	if (!(irmp_data.flags & IRMP_FLAG_REPETITION))											// first check if the IR command is repeated
	{
		RepeatCounter = 0;																	// new command received, reset RepeatCounter
	}																	
	else
	{	
		RepeatCounter++;																	// still the same command, inc RepeatCounter
	}																

	if ((RepeatCounter == 0) | ( RepeatCounter >= MinRepeats))								// only send interrupt if first command, or Repeatcounter >= MinRepeats
	{
		if (RepeatCounter >= MinRepeats)	
			RepeatCounter = MinRepeats;														// fix overflow for long key push

		memcpy(&replyBuf[0], &NewIRCodeAvailable, sizeof(uchar));							// copy report id to reply buffer
		memcpy(&replyBuf[1], &irmp_data, sizeof(irmp_data)); 								// copy received IR code to reply buffer

	    usbSetInterrupt(&replyBuf[0], sizeof(irmp_data) + sizeof(uchar));					// send ReportID + IR data
	}
}
/* ------------------------------------------------------------------------- */
/* function to log IR signals and transfer to host by USB
*/
#if IRMP_LOGGING
void irmp_log_usb (unsigned short len)
{
	memcpy(&replyBuf[0], &NewLogAvailable, sizeof(uchar));								// copy report id to reply buffer	
	memcpy(&replyBuf[1], &len, sizeof(unsigned short));
	
	while (!usbInterruptIsReady()) usbPoll();											// check if USB int is ready
		usbSetInterrupt(&replyBuf[0], sizeof(uchar) + sizeof(unsigned short));			// send ReportID + IR data		
}
#endif
/* ------------------------------------------------------------------------- */
/* main function
*/
int main(void)
{

	uchar   i;
    /* Even if you don't use the watchdog, turn it off here. On newer devices,
     * the status of the watchdog (on/off, period) is PRESERVED OVER RESET!
     */
	wdt_disable();																						// first disable watchdog
    /* RESET status: all port bits are inputs without pull-up.
     * That's the way we need D+ and D-. Therefore we don't need any
     * additional hardware initialization.
     */

	#if USE_BOOTLOADER
	eeprom_write_block(&DisableBootloader, (uchar *)0 + AdressBootloader, sizeof(uchar));
	#endif


    wdt_enable(WDTO_1S);																				// enable again watchdog

	init_io();

	memset(&irmp_data, 0x00, sizeof(irmp_data));  														// clear irmp_data

	memset(&trained_irmp_data, 0x00, sizeof(trained_irmp_data));										// clear trained_irmp_data

	irmp_init();                                                            							// initialize irmp code
	timer_init();                                                           							// initialize timer

	led1Off();
	led2On();

    usbDeviceDisconnect();  																			/* enforce re-enumeration, do this while interrupts are disabled! */
    i = 0;
    while(--i){             																			/* fake USB disconnect for > 500 ms */
        wdt_reset();
        _delay_ms(5);
    }
    usbDeviceConnect();

    usbInit();																							// initialize v-usb
    sei();																								// enable global int

	#if USE_PowerOnFunction
		/* read stored variables, use uchar i for temp buffer */
		eeprom_read_block(&i, (uchar *)0 +AdressPowerOn, sizeof(PowerOnEnabled));						// read if PowerOn is already set

		if ( i == 0xFF )
		{																								// power on isn't stored yet, save the init value
			eeprom_write_block(&PowerOnEnabled, (uchar *)0 +AdressPowerOn, sizeof(PowerOnEnabled));		// set PowerOn Enabled to default
		}else{ memcpy(&PowerOnEnabled, &i, sizeof(PowerOnEnabled)); }									// update actual value
	#endif	
	
	eeprom_read_block(&i, (uchar *)0 +AdressMinRepeats, sizeof(MinRepeats));							// read if MinRepeats is already set

	if ( i == 0xFF )
	{																									// MinRepeats isn't stored yet, save the init value
		eeprom_write_block(&MinRepeats, (uchar *)0 +AdressMinRepeats, sizeof(MinRepeats));				// set MinRepeats to default: 5
	}else{ memcpy(&MinRepeats, &i, sizeof(MinRepeats)); }												// update actual value


	eeprom_read_block(&trained_irmp_data, (uchar *)0 +AdressTrainedCode, sizeof(irmp_data));			// read last saved trained IR code in eeprom

    for(;;){                			/* main event loop */
        wdt_reset();

	    if (irmp_get_data (&irmp_data))																	// check if new IR code is aviable
	    {
	        /* ir signal decoded, do something here...*/
	        /* irmp_data.protocol is the protocol, see irmp.h*/
	        /* irmp_data.address is the address/manufacturer code of ir sender*/
	        /* irmp_data.command is the command code*/
			/* */
			#if USE_PowerOnFunction
				if ((trained_irmp_data.protocol != 0xFF) & (trained_irmp_data.protocol != 0x00))		// check if code is already trained:
				{
					// IR code trained,
					// if PowerOn function is enabled check it
					if (PowerOnEnabled)
					{
						//compare trained code with last received code
						if (memcmp(&irmp_data, &trained_irmp_data, sizeof(irmp_data) - 1) == 0)				 
						{
							SWITCH_PORT ^= _BV(SWITCH_BIT);												// switch on output pin form ~250ms
						    while(--i)
							{
						        wdt_reset();															// watchdog reset
								usbPoll();																// do a USB poll
						        _delay_us(500);															// delay
						    }
							SWITCH_PORT ^= _BV(SWITCH_BIT);												// switch off output pin
						}else{ SendINTData(); }															// set flag for received new IR code					
					}else{ SendINTData(); }																// set flag for received new IR code				
				}else{
					eeprom_write_block(&irmp_data,(uchar *)0 + AdressTrainedCode, sizeof(irmp_data));	// no IR code trained, save it:		
					memcpy(&trained_irmp_data, &irmp_data, sizeof(irmp_data));							// update trained_irmp_data
				}
			#else
				SendINTData();
			#endif
			
			led1On();																					// toggle led
			_delay_us(500);
			led1Off();
	    }
        usbPoll();																						// do a USB poll
    }
    return 0;
}

/* ------------------------------------------------------------------------- */

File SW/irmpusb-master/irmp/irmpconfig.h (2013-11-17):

/*---------------------------------------------------------------------------------------------------------------------------------------------------
 * irmpconfig.h
 *
 * DO NOT INCLUDE THIS FILE, WILL BE INCLUDED BY IRMP.H!
 *
 * Copyright (c) 2009-2013 Frank Meyer - frank(at)fli4l.de
 *
 * $Id: irmpconfig.h,v 1.98 2013/01/17 07:33:13 fm Exp $
 *
 * ATMEGA88 @ 8 MHz
 *
 * This program is free software; you can redistribute it and/or modify
 * it under the terms of the GNU General Public License as published by
 * the Free Software Foundation; either version 2 of the License, or
 * (at your option) any later version.
 *---------------------------------------------------------------------------------------------------------------------------------------------------
 */

#ifndef _IRMPCONFIG_H_
#define _IRMPCONFIG_H_

#ifndef _IRMP_H_
#  error please include only irmp.h, not irmpconfig.h
#endif

/*---------------------------------------------------------------------------------------------------------------------------------------------------
 * Change F_INTERRUPTS if you change the number of interrupts per second,
 * Normally, F_INTERRUPTS should be in the range from 10000 to 15000, typical is 15000
 * A value above 15000 costs additional program space, absolute maximum value is 20000.
 *---------------------------------------------------------------------------------------------------------------------------------------------------
 */
#ifndef F_INTERRUPTS
#  define F_INTERRUPTS                          15000   // interrupts per second, min: 10000, max: 20000, typ: 15000
#endif

/*---------------------------------------------------------------------------------------------------------------------------------------------------
 * Change settings from 1 to 0 if you want to disable one or more decoders.
 * This saves program space.
 *
 * 1 enable  decoder
 * 0 disable decoder
 *
 * The standard decoders are enabled per default.
 * Less common protocols are disabled here, you need to enable them manually.
 *
 * If you want to use FDC or RCCAR simultaneous with RC5 protocol, additional program space is required.
 * If you don't need RC5 when using FDC/RCCAR, you should disable RC5.
 * You cannot enable both DENON and RUWIDO, only enable one of them.
 *---------------------------------------------------------------------------------------------------------------------------------------------------
 */

// typical protocols, disable here!             Enable  Remarks                 F_INTERRUPTS            Program Space
#define IRMP_SUPPORT_SIRCS_PROTOCOL             1       // Sony SIRCS           >= 10000                 ~150 bytes
#define IRMP_SUPPORT_NEC_PROTOCOL               1       // NEC + APPLE          >= 10000                 ~300 bytes
#define IRMP_SUPPORT_SAMSUNG_PROTOCOL           1       // Samsung + Samsung32  >= 10000                 ~300 bytes
#define IRMP_SUPPORT_MATSUSHITA_PROTOCOL        0       // Matsushita           >= 10000                  ~50 bytes
#define IRMP_SUPPORT_KASEIKYO_PROTOCOL          0       // Kaseikyo             >= 10000                 ~250 bytes
#define IRMP_SUPPORT_DENON_PROTOCOL             0       // DENON, Sharp         >= 10000                 ~250 bytes

// more protocols, enable here!                 Enable  Remarks                 F_INTERRUPTS            Program Space
#define IRMP_SUPPORT_RC5_PROTOCOL               1       // RC5                  >= 10000                 ~250 bytes
#define IRMP_SUPPORT_RC6_PROTOCOL               1       // RC6 & RC6A           >= 10000                 ~250 bytes
#define IRMP_SUPPORT_JVC_PROTOCOL               0       // JVC                  >= 10000                 ~150 bytes
#define IRMP_SUPPORT_NEC16_PROTOCOL             1       // NEC16                >= 10000                 ~100 bytes
#define IRMP_SUPPORT_NEC42_PROTOCOL             1       // NEC42                >= 10000                 ~300 bytes
#define IRMP_SUPPORT_IR60_PROTOCOL              0       // IR60 (SDA2008)       >= 10000                 ~300 bytes
#define IRMP_SUPPORT_GRUNDIG_PROTOCOL           0       // Grundig              >= 10000                 ~300 bytes
#define IRMP_SUPPORT_SIEMENS_PROTOCOL           1       // Siemens Gigaset      >= 15000                 ~550 bytes
#define IRMP_SUPPORT_NOKIA_PROTOCOL             0       // Nokia                >= 10000                 ~300 bytes
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

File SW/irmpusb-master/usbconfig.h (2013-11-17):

/* Name: usbconfig.h
 * Project: V-USB, virtual USB port for Atmel's(r) AVR(r) microcontrollers
 * Author: Christian Starkjohann
 * Creation Date: 2005-04-01
 * Tabsize: 4
 * Copyright: (c) 2005 by OBJECTIVE DEVELOPMENT Software GmbH
 * License: GNU GPL v2 (see License.txt), GNU GPL v3 or proprietary (CommercialLicense.txt)
 * This Revision: $Id: usbconfig-prototype.h 785 2010-05-30 17:57:07Z cs $
 */

#ifndef __usbconfig_h_included__
#define __usbconfig_h_included__

#include "configUSBIRRemoteReceiver.h"

/*
General Description:
This file is an example configuration (with inline documentation) for the USB
driver. It configures V-USB for USB D+ connected to Port D bit 2 (which is
also hardware interrupt 0 on many devices) and USB D- to Port D bit 4. You may
wire the lines to any other port, as long as D+ is also wired to INT0 (or any
other hardware interrupt, as long as it is the highest level interrupt, see
section at the end of this file).
*/

/* ---------------------------- Hardware Config ---------------------------- */

#define USB_CFG_IOPORTNAME      B
/* This is the port where the USB bus is connected. When you configure it to
 * "B", the registers PORTB, PINB and DDRB will be used.
 */
#define USB_CFG_DMINUS_BIT      0
/* This is the bit number in USB_CFG_IOPORT where the USB D- line is connected.
 * This may be any bit in the port.
 */
#define USB_CFG_DPLUS_BIT       1
/* This is the bit number in USB_CFG_IOPORT where the USB D+ line is connected.
 * This may be any bit in the port. Please note that D+ must also be connected
 * to interrupt pin INT0! [You can also use other interrupts, see section
 * "Optional MCU Description" below, or you can connect D- to the interrupt, as
 * it is required if you use the USB_COUNT_SOF feature. If you use D- for the
 * interrupt, the USB interrupt will also be triggered at Start-Of-Frame
 * markers every millisecond.]
 */
#define USB_CFG_CLOCK_KHZ       (F_CPU/1000)
/* Clock rate of the AVR in kHz. Legal values are 12000, 12800, 15000, 16000,
 * 16500, 18000 and 20000. The 12.8 MHz and 16.5 MHz versions of the code
 * require no crystal, they tolerate +/- 1% deviation from the nominal
 * frequency. All other rates require a precision of 2000 ppm and thus a
 * crystal!
 * Since F_CPU should be defined to your actual clock rate anyway, you should
 * not need to modify this setting.
 */
#define USB_CFG_CHECK_CRC       0
/* Define this to 1 if you want that the driver checks integrity of incoming
 * data packets (CRC checks). CRC checks cost quite a bit of code size and are
 * currently only available for 18 MHz crystal clock. You must choose
 * USB_CFG_CLOCK_KHZ = 18000 if you enable this option.
 */

/* ----------------------- Optional Hardware Config ------------------------ */

/* #define USB_CFG_PULLUP_IOPORTNAME   D */
/* If you connect the 1.5k pullup resistor from D- to a port pin instead of
 * V+, you can connect and disconnect the device from firmware by calling
 * the macros usbDeviceConnect() and usbDeviceDisconnect() (see usbdrv.h).
 * This constant defines the port on which the pullup resistor is connected.
 */
/* #define USB_CFG_PULLUP_BIT          4 */
/* This constant defines the bit number in USB_CFG_PULLUP_IOPORT (defined
 * above) where the 1.5k pullup resistor is connected. See description
 * above for details.
 */

/* --------------------------- Functional Range ---------------------------- */
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

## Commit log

2013-03-21 1st Upload
    [Add-OnV5.brd, Add-OnV5.sch]
2013-03-24 Mirrored Plug
    for using the the cable of USB-ASP...
    [Add-OnV13.brd, Add-OnV13.sch]
2013-03-24 Mini-Version
    Use without Cable
    [MiniAdd-OnV10.brd, MiniAdd-OnV10.sch]
2013-03-29 Large
    +Cleanup
    [Add-OnV13.brd, Add-OnV13.sch, MiniAdd-OnV10.brd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]
2013-04-12 Final Layout
    [Add-OnV12.brd, Add-OnV12.sch, Add-OnV13.brd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]
2013-05-05 Missing BRD
    [UsbAsp_IR-Gross-41.brd]
2013-11-20 Mini V1.1
    [Add-OnV15.brd, Add-OnV15.sch, Mini-Small-Parts.xls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]
2013-12-19 Fix PortD
    PORTD &=~(1<<PD2); /* deactivate pull-up on int0 line */
    [main.c]
2014-01-03 IR-Control: added "repeat"
    Thanks to Wirbel und Bleifuss2
2014-01-04 Fix Repeat Rate
    Thanks again to Wirbel + Bleifuss2
2014-01-25 Repeat rate fix by woggle
    From here
    http://www.vdr-portal.de/board16-video-disk-recorder/board4-vdr-installation/p1183244-gel%C3%B6st-samsung-fernbedienung-mit-usb-ir-receiver-einrichten/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
2014-03-31 New Layout V2
    [Add-OnV20d.brd, Add-OnV20d.sch]
2014-05-13 Optimized V2
    [Add-OnV20-final.brd, Add-OnV20-final.sch]
2014-11-01 Slotblech (Draft)
    [Slotblech-V01.brd, Slotblech-V01.sch]
2014-11-01 FiX Repeat Rate by hitman47
    Source:
    http://www.easy-vdr.de/forum/index.php?topic=16032.msg153985#msg153985
